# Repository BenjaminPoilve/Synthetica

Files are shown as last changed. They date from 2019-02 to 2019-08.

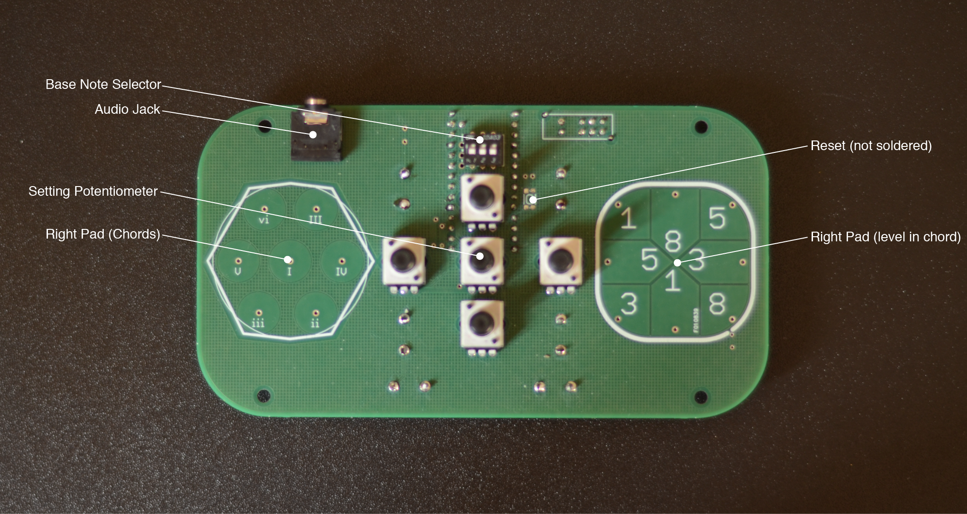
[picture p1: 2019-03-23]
Media/parts-02.png

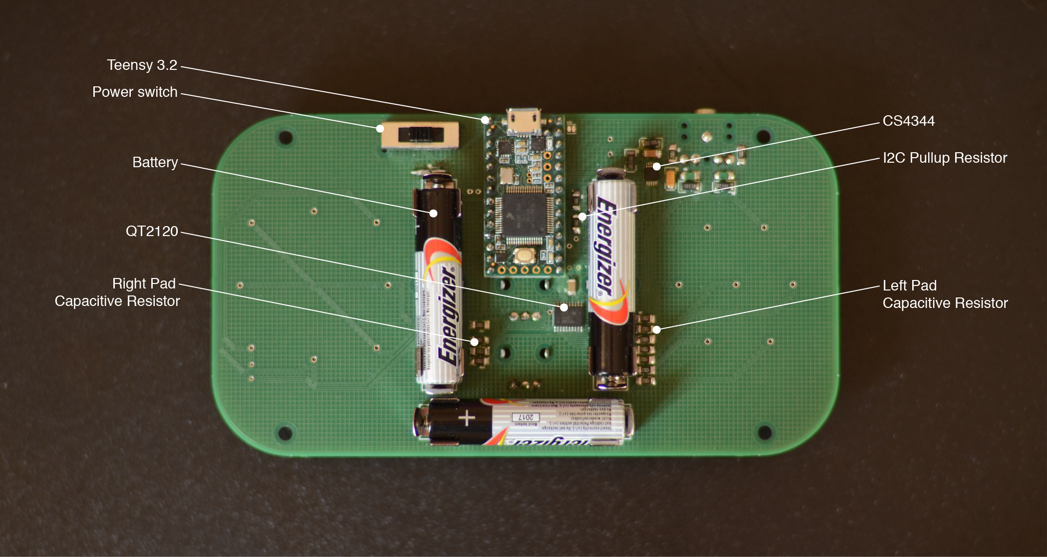
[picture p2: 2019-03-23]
Media/parts-01.png

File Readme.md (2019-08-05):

# Synthetica

**Read about this project [here](https://www.benjaminpoilve.com/projects/synthetica.html)**

The basic idea is to create a simple instrument, with on one side the chord selection, and on the other side the note selection (within that chord). 

I will use a teensy as main board for a few reason:

* Teensy are awesome
* Teensy audio library is awesome

Will be major only, minor by transposition as with the harmonica. Choice of chords, look [here](https://www.hooktheory.com/blog/i-analyzed-the-chords-of-1300-popular-songs-for-patterns-this-is-what-i-found/)

## BOM

The teensy 3.2 will do:

* I2S output (Pin 9,11,22,23)
* I2C to touch chip (Pin 18, 19)
* 5 setting potentiometer (Pin 14, 16, 17 ,20)
* 3 switch for fondamental select (Pin 2, 3, 4)
* 1 calibrate switch (Pin 5)
* 1 select switch (automatically go from jack to USB) (Pin 6)

#### Summing Up

| Part Name  |  Value | Reference document | Count | 
|---|---|---|---|
|  Teensy 3.2  | None  | [:link:](https://www.mouser.fr/ProductDetail/Adafruit/2756?qs=sGAEpiMZZMuSK2mCDyT9crBR9UUNDPltQqpZaqADC8g%3d) | 1  | 
| Potentiometer |  100K  | [:link:](https://www.mouser.fr/ProductDetail/Bourns/PTV09A-4020U-B104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)  | 5  |  
| 3 DIP switch | None  | [:link:](https://www.mouser.fr/ProductDetail/CK/SDA03H1BD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)  | 1  |  
| DP3T switch | None  | [:link:](https://www.mouser.fr/ProductDetail/CK/OS203012MU5QP1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)  | 1  |  
|CS4344| None  | [:link:](https://www.mouser.fr/ProductDetail/Cirrus-Logic/CS4344-CZZ?qs=sGAEpiMZZMuYaq4aOfOV%252bEKBckiASbBM)  | 1  |  
| QT2120 | None  | [:link:](https://www.mouser.fr/ProductDetail/Microchip-Technology-Atmel/AT42QT2120-XUR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)  | 1  | 
|KMR2 switch | None  | [:link:](https://www.mouser.fr/ProductDetail/CK/KMR231NGLFS?qs=sGAEpiMZZMsgGjVA3toVBPoYbSFtFlEEZ%2foF5FrvAI8%3d)  | 1  | 
|AAA Holder | None  | [:link:](https://www.mouser.fr/ProductDetail/Keystone-Electronics/82?qs=sGAEpiMZZMsQtlBhqKq43YbiTvCk46ni)  | 6  | 
| Jack Connector | None | [:link:](https://www.mouser.fr/ProductDetail/Switchcraft/35RAPC4BHN2?qs=sGAEpiMZZMv0W4pxf2HiV3fTUvSc3cBd2jSbOSYtPwc%3d) | 1|
| Capacitor | 0.1uf | [:link:](https://www.mouser.fr/ProductDetail/KEMET/C1206C104MMREC7210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) | 2|
| Polarised capacitor | 1uf | [:link:](https://www.mouser.fr/ProductDetail/AVX/F971E105MAAHT3?qs=sGAEpiMZZMukHu%252bjC5l7Yco8kKEM9uRbb54cngRv8Go%3d) | 1|
| Polarised capacitor | 3.3uf | [:link:](https://www.mouser.fr/ProductDetail/AVX/F971C335MAAHT3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) | 3|
| Polarised capacitor | 10uf | [:link:](https://www.mouser.fr/ProductDetail/KEMET/T491A106K016AT7280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) | 1|
| Diode | None | [:link:](https://www.mouser.fr/ProductDetail/ROHM-Semiconductor/RB160MM-40TFTR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) | 1|
| Resistor | 470 | [:link:](https://www.mouser.fr/ProductDetail/KOA-Speer/SG73G2BTTD4700D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) | 2|
| Resistor | 2k2 | [:link:](https://www.mouser.fr/ProductDetail/TE-Connectivity-Holsworthy/CRGP1206F2K2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) | 2|
| Resistor | 10k | [:link:](https://www.mouser.fr/ProductDetail/Yageo/AC1206FR-1010KL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) | 13|

## Issues, and feedbacks

#### From First PCB

* Get longer pad traces for chips. This version is reflow friendly, but hard to hand solder
* The interruptor is backward, issue with trace
* The voltage drop of the diode is too high! Wrong part? Had to bypass it.
* Pots are too big. Should change version
* Should use two AAA, use a voltage converter
* Should put component more to the center to make the side more easy to cover
* Issue with jack trace, does not go through PCB hole.
* See if there is feeback on the sensors.
* Should really try to avoid vias on capacitive lines. At least put them closer to the center

#### Other

* Issue with [USB](https://forum.pjrc.com/threads/54239-USB-Audio-Clicking-Noise/page3?highlight=noise+audio)
* Probably needs to have a status led

## Thanks and people that helped

* Everybody that helped me on [that thread](https://forum.pjrc.com/threads/55137-I2S-output-with-CS4344) 
* @otem for its polysynth

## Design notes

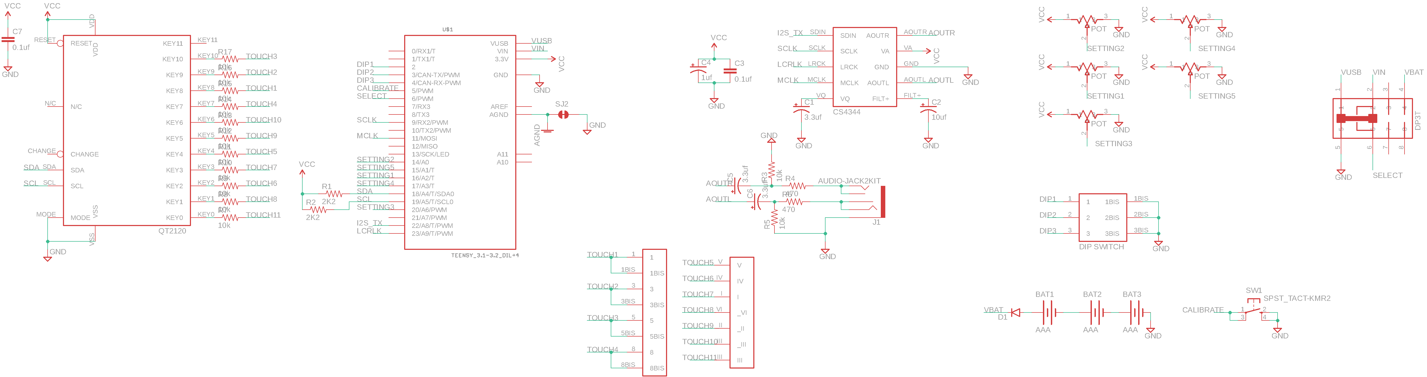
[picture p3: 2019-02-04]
Hardware/SCHEMATICS/Schematics.png

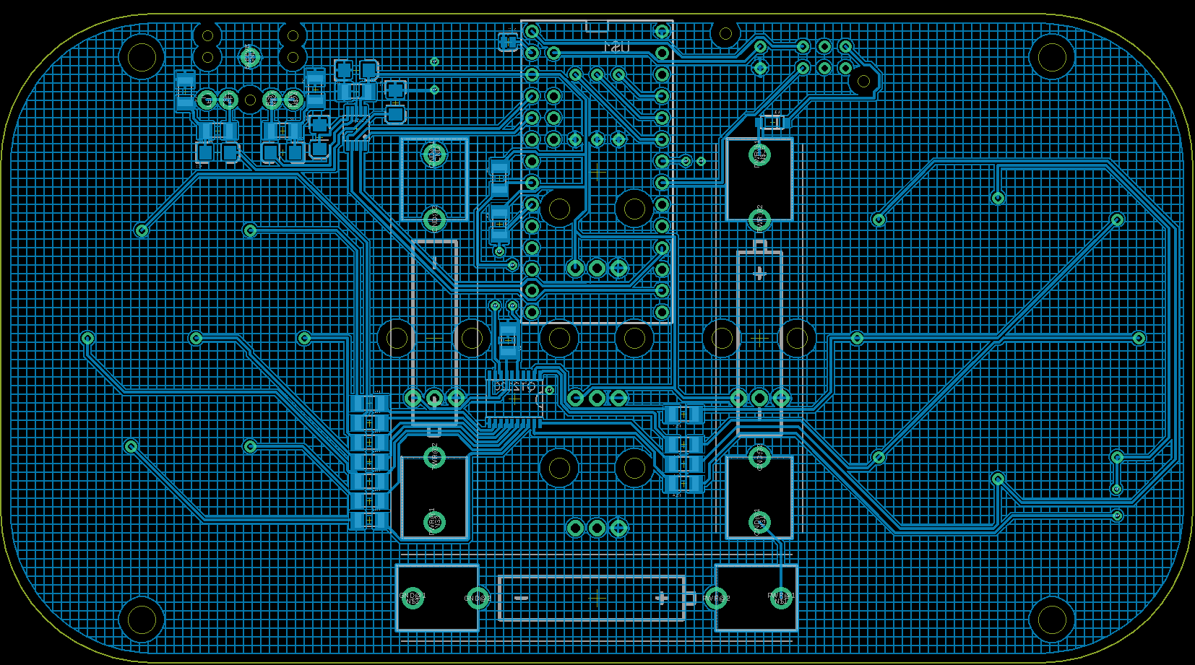
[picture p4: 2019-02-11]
Hardware/BOARD/bottom.png

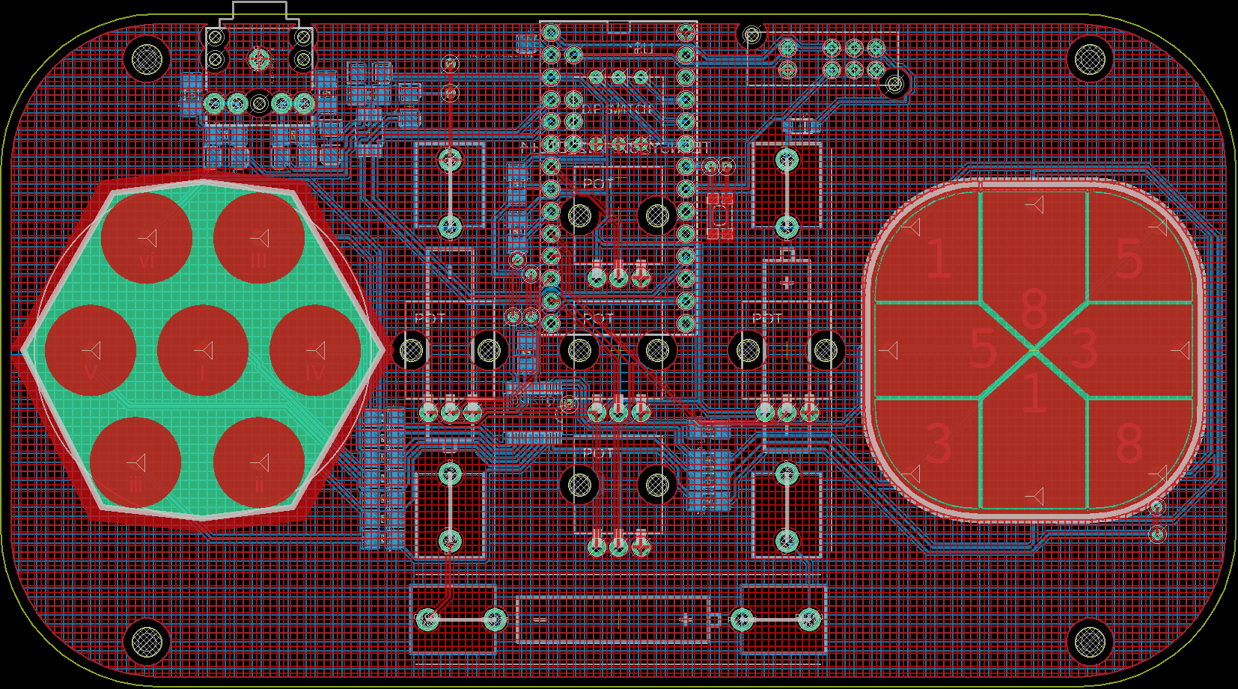
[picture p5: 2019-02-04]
Hardware/BOARD/board.png

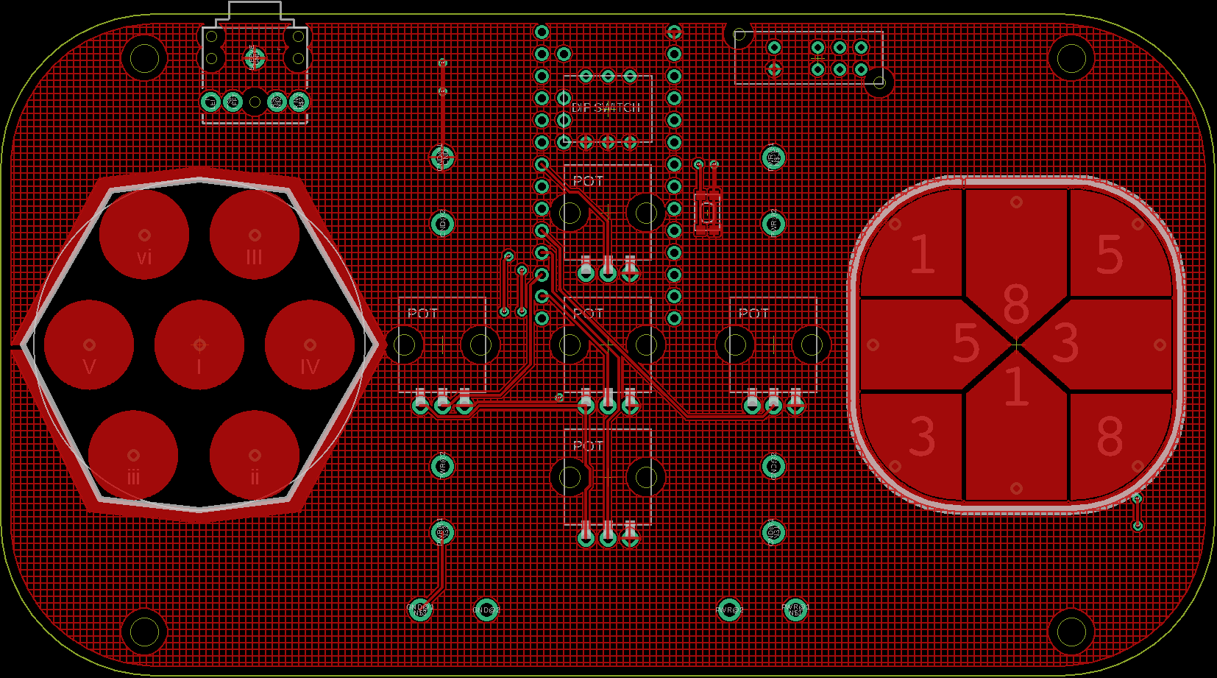
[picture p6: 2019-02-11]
Hardware/BOARD/top.png

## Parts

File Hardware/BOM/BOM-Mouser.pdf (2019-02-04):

Produits (https://www.mouser.fr/Electronic-Components/) | Fabricants (https://www.mouser.fr/supplierpage/) | Plus (https://www.mouser.fr/sitemap/) | Historique des commandes (https://www.mouser.fr/OrderHistory/OrderHistoryLogin.aspx) | Mon compte (https://www.mouser.fr/MyMouser/AccountSummary.aspx) | | | Déconnexion

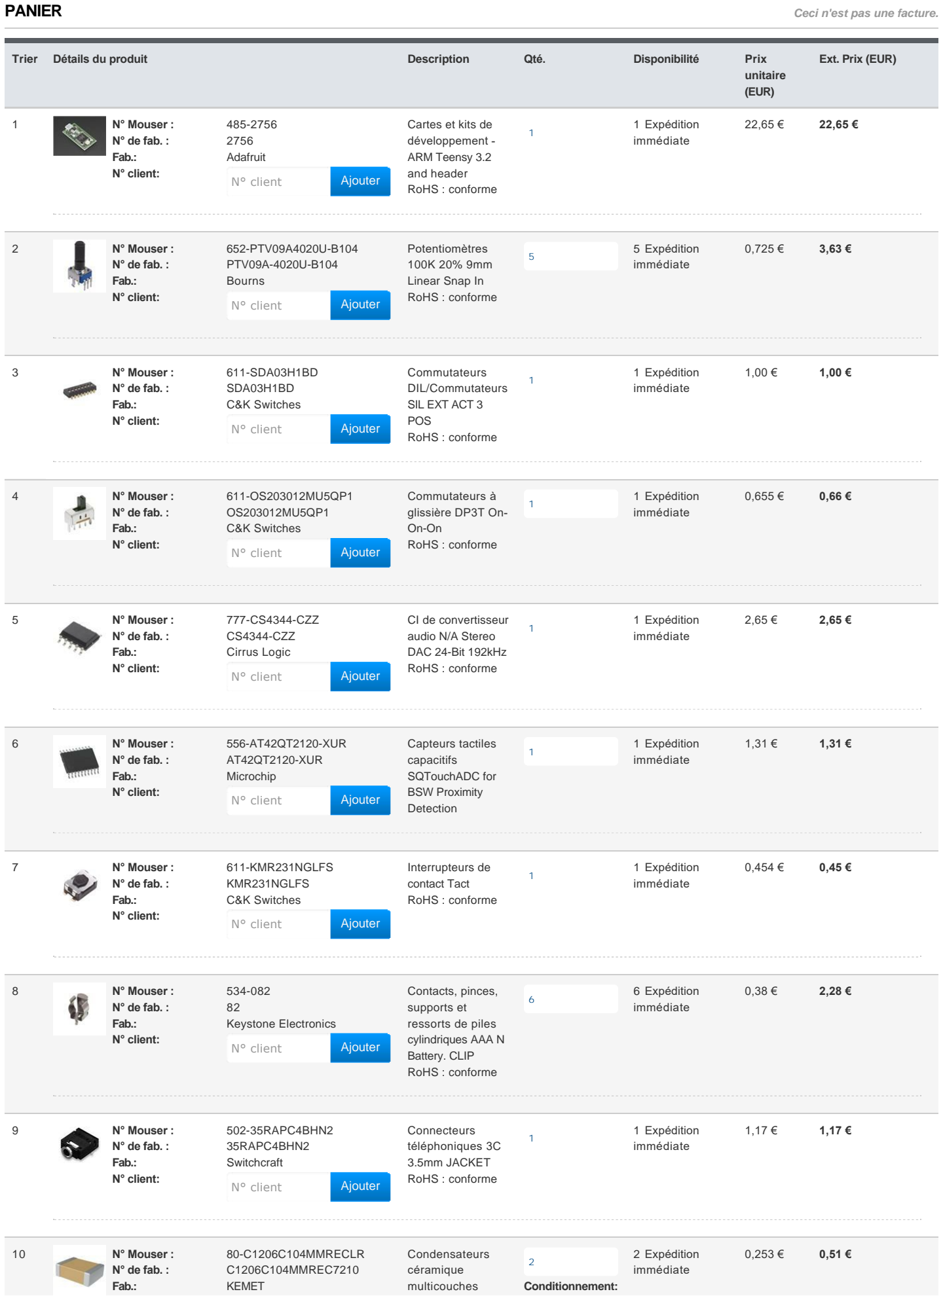
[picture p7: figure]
Trier; Détails du produit; Description; Qté.; Disponibilité; Prix; unitaire; (EUR); Ext. Prix (EUR); PANIER; Ceci n'est pas une facture.; N° Mouser :; N° de fab. :; Fab.:; Adafruit; N° client:; N° client; Ajouter; Cartes et kits de; développement; ARM Teensy 3.2; and header; RoHS : conforme; 1 Expédition; immédiate; 652-PTV09A4020U-B104; PTV09A-4020U-B104; Bourns; Potentiomètres; Linear Snap In; 5 Expédition; 611-SDA03H1BD; SDA03H1BD; C&K Switches; Commutateurs; DIL/Commutateurs; SIL EXT ACT 3; POS; Commutateurs à; glissière DP3T On-; 777-CS4344-CZZ; CS4344-CZZ; Cirrus Logic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

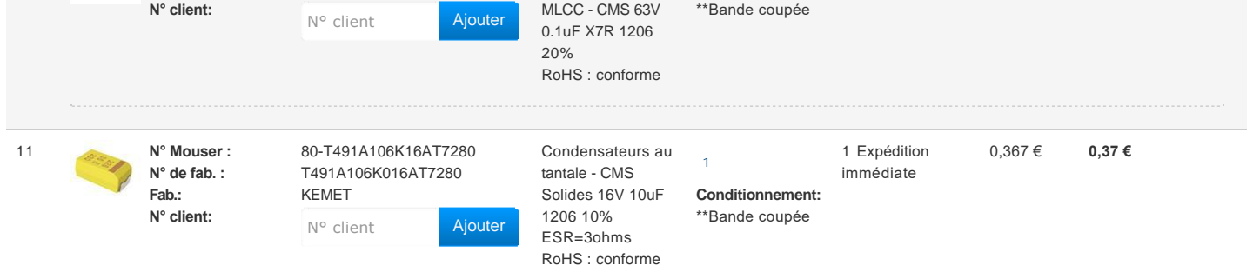
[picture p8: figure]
N° client:; N° client; Ajouter; MLCC - CMS 63V; RoHS : conforme; **Bande coupée; N° Mouser :; N° de fab. :; Fab.:; KEMET; Condensateurs au; tantale - CMS; Solides 16V 10uF; ESR=3ohms; Conditionnement:; 1 Expédition; immédiate
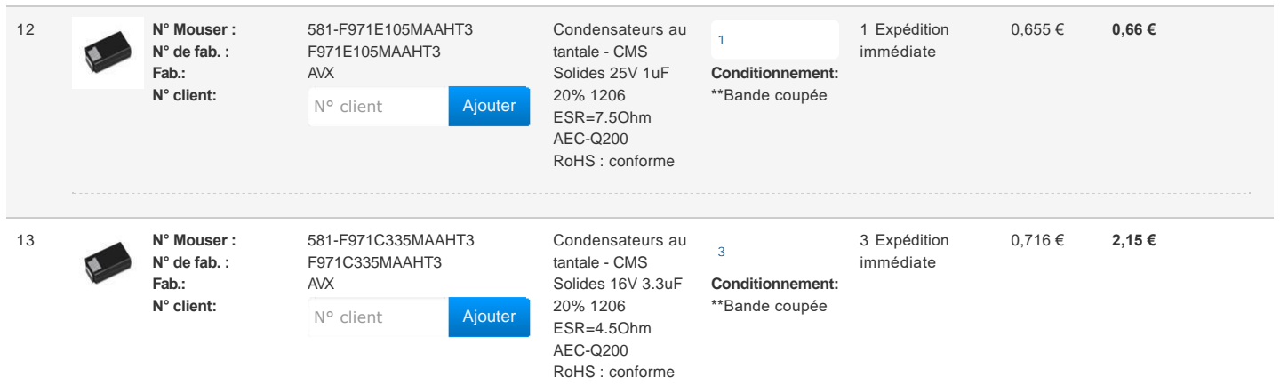
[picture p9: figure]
N° Mouser :; 581-F971E105MAAHT3; N° de fab. :; F971E105MAAHT3; Fab.:; AVX; N° client:; N° client; Ajouter; Condensateurs au; tantale - CMS; Solides 25V 1uF; ESR=7.5Ohm; AEC-Q200; RoHS : conforme; Conditionnement:; **Bande coupée; 1 Expédition; immédiate; 581-F971C335MAAHT3; F971C335MAAHT3; Solides 16V 3.3uF; ESR=4.5Ohm; 3 Expédition
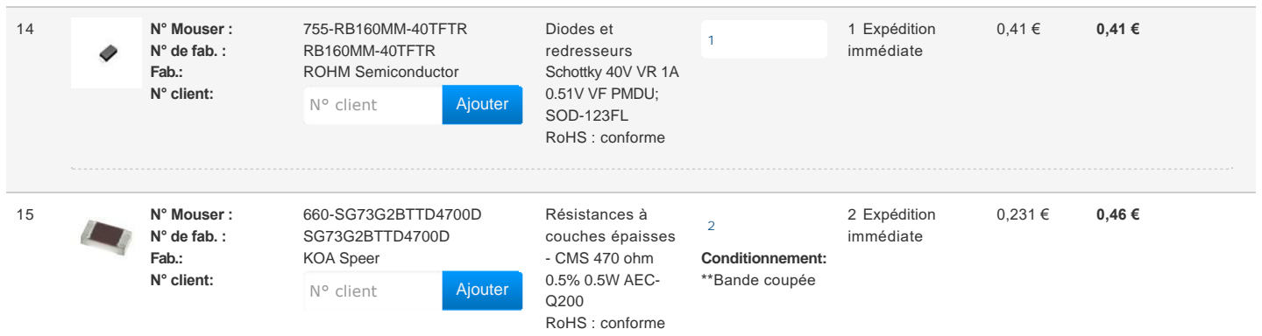
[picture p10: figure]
N° Mouser :; 755-RB160MM-40TFTR; N° de fab. :; RB160MM-40TFTR; Fab.:; ROHM Semiconductor; N° client:; N° client; Ajouter; Diodes et; redresseurs; Schottky 40V VR 1A; 0.51V VF PMDU;; SOD-123FL; RoHS : conforme; 1 Expédition; immédiate; 660-SG73G2BTTD4700D; SG73G2BTTD4700D; KOA Speer; Résistances à; couches épaisses; - CMS 470 ohm; 0.5% 0.5W AEC-; Conditionnement:; **Bande coupée; 2 Expédition
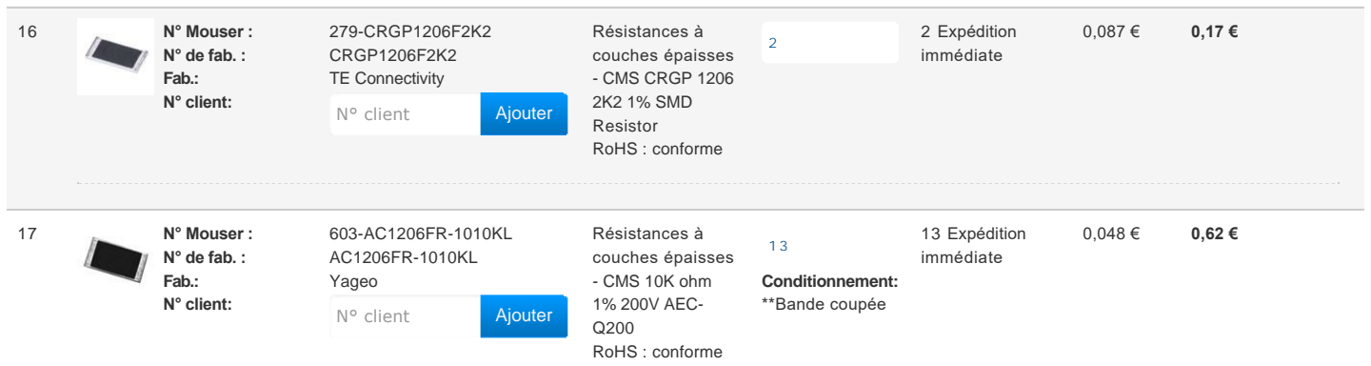
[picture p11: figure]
N° Mouser :; 279-CRGP1206F2K2; N° de fab. :; CRGP1206F2K2; Fab.:; TE Connectivity; N° client:; N° client; Ajouter; Résistances à; couches épaisses; - CMS CRGP 1206; 2K2 1% SMD; Resistor; RoHS : conforme; 2 Expédition; immédiate; Yageo; - CMS 10K ohm; 1% 200V AEC-; Conditionnement:; **Bande coupée; 13 Expédition

En soumettant votre commande, vous acceptez ces conditions. (https://www.mouser.fr/saleterms)
Pour plus d'informations sur la disponibilité, cliquez sur le numéro de référence Mouser

**Tous les articles MouseReel™ ne peuvent être ni annulés ni retournés.

Incoterms :DDP
Tous les prix incluent les taxes et les droits de douane pour les modes d'expédition sélectionnés.
Livraison gratuite pour la plupart des commandes supérieures à 50 € (EUR)
Total des articles : | 41,15 €
Estimation des frais d'expédition : | 20,00 € FedEx Inte
Sous-total : | 61,15 €

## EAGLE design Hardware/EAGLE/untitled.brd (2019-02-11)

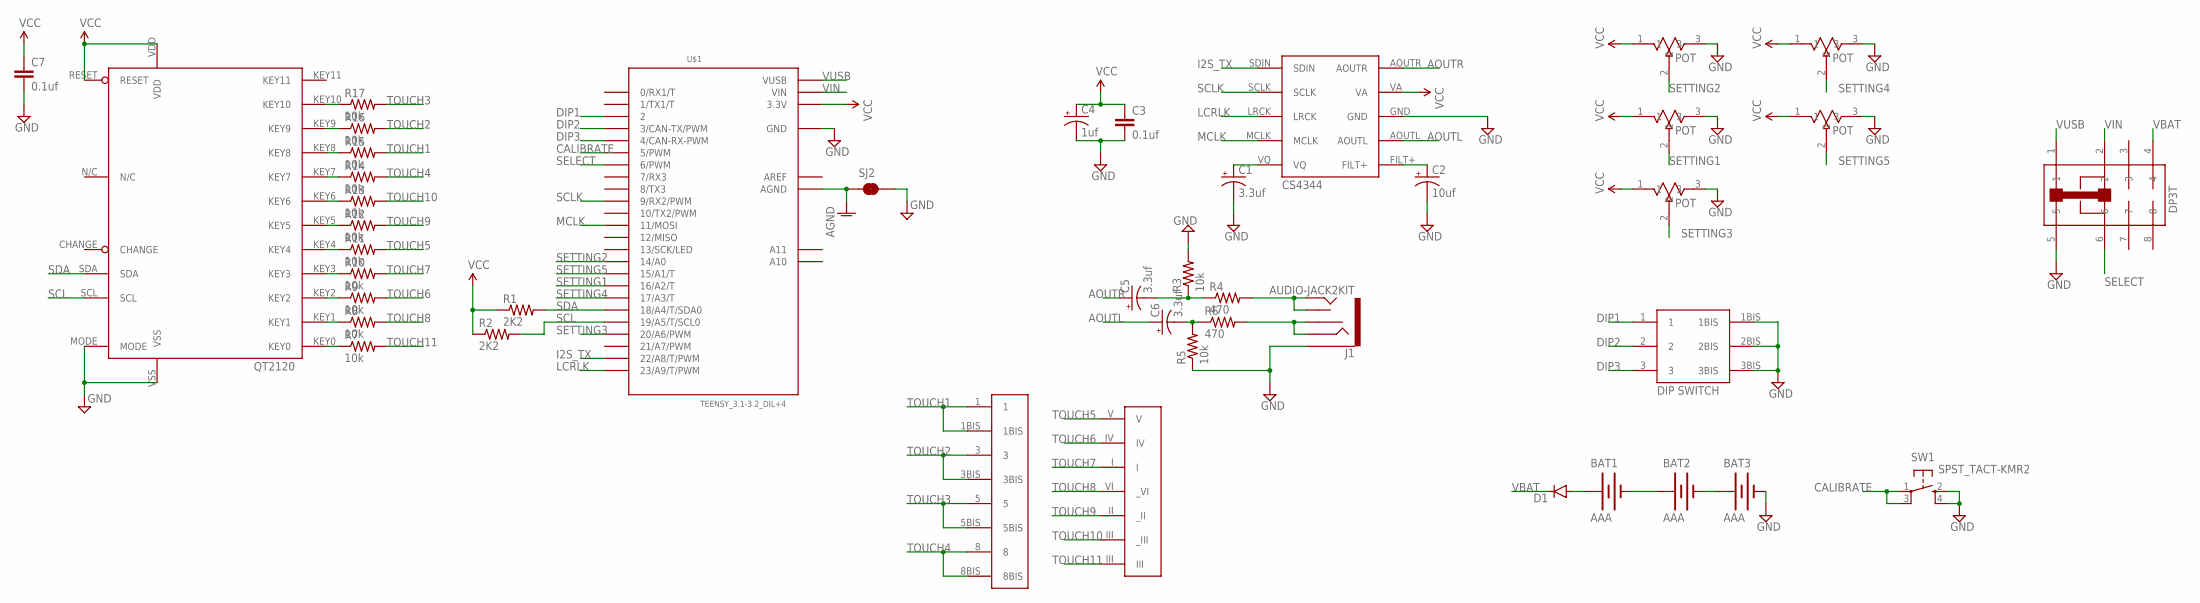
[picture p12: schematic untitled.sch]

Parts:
BAT1, BAT2, BAT3: AAA; BATTERY-AAA-KIT
C1, C5, C6: 3.3uf; EIA3216
C2: 10uf; EIA3216
C3, C7: 0.1uf; 1206
C4: 1uf; EIA3216
D1: DIODESOD123; SOD-123
DIP1: SDA03H1BD
DP3T1: OS203012MU5QP1
J1: AUDIO-JACK2KIT; AUDIO-JACK-KIT
POT2, POT3, POT5: PTV09A-4020U-B104
R1, R2: 2K2; 1206
R3, R5, R7, R8, R9, R10, R11, R12, R13, R14, R15, R16, R17: 10k; 1206
R4, R6: 470; 1206
SJ2: JUMPER-PAD-2-NC_BY_TRACE; PAD-JUMPER-2-NC_BY_TRACE_YES_SILK
SW1: SPST_TACT-KMR2; KMR2
SWEEP: PTV09A-4020U-B104
U1: CS4344
U$1: TEENSY_3.1-3.2_DIL+4; TEENSY_3.0-3.2&LC_DIL+4
U$2: QT2120
U$4: NOTEPAD
U$5: CHORDPAD
VOLUME: PTV09A-4020U-B104

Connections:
AGND: SJ2.1, U$1.AGND
AOUTL: C6.A (+), U1.AOUTL
AOUTR: C5.A (+), U1.AOUTR
AREF: U$1.AREF
CALIBRATE: SW1.1, SW1.3 (P1), U$1.5 (5/PWM)
DIP1: DIP1.1, U$1.2
DIP2: DIP1.2, U$1.3 (3/CAN-TX/PWM)
DIP3: DIP1.3, U$1.4 (4/CAN-RX-PWM)
GND: BAT3.GND@1 (-), C1.C (-), C2.C (-), C3.2, C4.C (-), C7.2, DIP1.1BIS, DIP1.2BIS, DIP1.3BIS, DP3T1.5, J1.SLEEVE, POT2.3, POT3.3, POT5.3, R3.2, R5.1, SJ2.2, SW1.2 (S), SW1.4 (S1), SWEEP.3, U1.GND, U$1.GND, U$2.MODE, U$2.VSS, VOLUME.3
I2S_TX: U1.SDIN, U$1.22/A8 (22/A8/T/PWM)
LCRLK: U1.LRCK, U$1.23/A9 (23/A9/T/PWM)
LEFT: J1.TIP, J1.TSH, R4.2
MCLK: U1.MCLK, U$1.11 (11/MOSI)
unnamed: BAT1.GND@1 (-), BAT2.PWR@1 (+)
unnamed: C1.A (+), U1.VQ
unnamed: BAT2.GND@1 (-), BAT3.PWR@1 (+)
unnamed: C2.A (+), U1.FILT+
unnamed: C5.C (-), R3.1, R4.1
unnamed: C6.C (-), R5.2, R6.1
unnamed: R17.1, U$2.KEY10
unnamed: R16.1, U$2.KEY9
unnamed: R15.1, U$2.KEY8
unnamed: R14.1, U$2.KEY7
unnamed: R13.1, U$2.KEY6
unnamed: R12.1, U$2.KEY5
unnamed: R11.1, U$2.KEY4
unnamed: R10.1, U$2.KEY3
unnamed: BAT1.PWR@1 (+), D1.A
unnamed: R9.1, U$2.KEY2
unnamed: R8.1, U$2.KEY1
unnamed: R7.1, U$2.KEY0
unnamed: J1.RING, J1.RSH, R6.2
SCL: R2.2, U$1.19/A5 (19/A5/T/SCL0), U$2.SCL
SCLK: U1.SCLK, U$1.9 (9/RX2/PWM)
SDA: R1.2, U$1.18/A4 (18/A4/T/SDA0), U$2.SDA
SELECT: DP3T1.6, U$1.6 (6/PWM)
SETTING1: POT2.2, U$1.16/A2 (16/A2/T)
SETTING2: U$1.14/A0, VOLUME.2
SETTING3: POT3.2, U$1.20/A6 (20/A6/PWM)
SETTING4: SWEEP.2, U$1.17/A3 (17/A3/T)
SETTING5: POT5.2, U$1.15/A1 (15/A1/T)
TOUCH1: R15.2, U$4.1, U$4.1BIS
TOUCH2: R16.2, U$4.3, U$4.3BIS
TOUCH3: R17.2, U$4.5, U$4.5BIS
TOUCH4: R14.2, U$4.8, U$4.8BIS
TOUCH5: R11.2, U$5.V
TOUCH6: R9.2, U$5.IV
TOUCH7: R10.2, U$5.I
TOUCH8: R8.2, U$5._VI
TOUCH9: R12.2, U$5._II
TOUCH10: R13.2, U$5._III
TOUCH11: R7.2, U$5.III
VBAT: D1.C, DP3T1.4
VCC: C3.1, C4.A (+), C7.1, POT2.1, POT3.1, POT5.1, R1.1, R2.1, SWEEP.1, U1.VA, U$1.3.3V, U$2.RESET, U$2.VDD, VOLUME.1
VIN: DP3T1.2, U$1.VIN
VUSB: DP3T1.1, U$1.VUSB

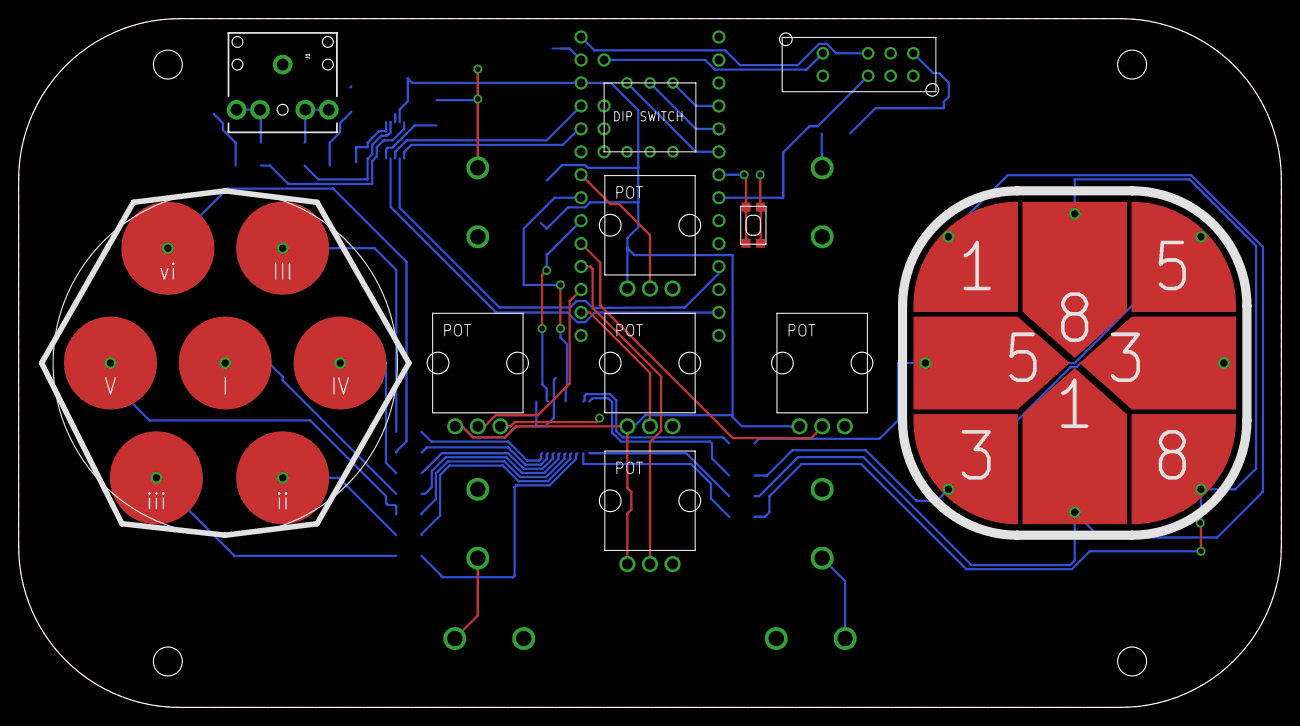
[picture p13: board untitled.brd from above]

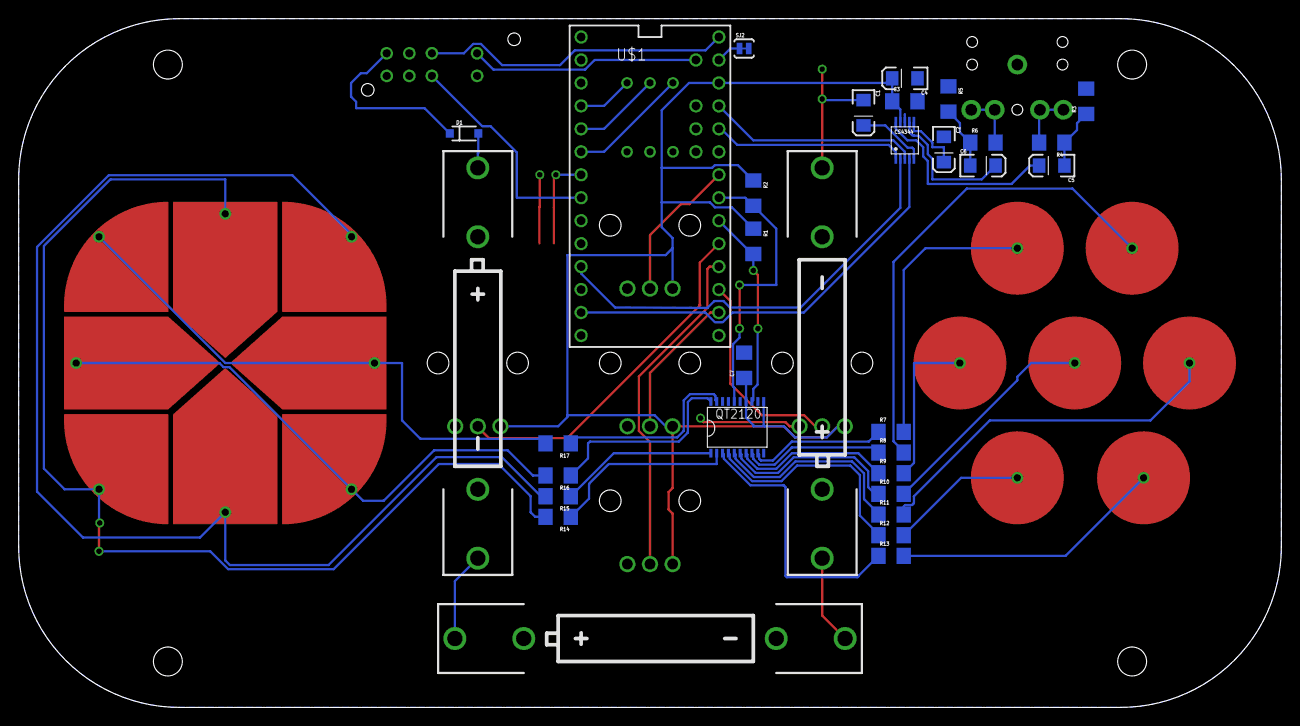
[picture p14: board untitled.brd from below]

Board: 2 copper layers, 139.7 x 76.2 mm, 43 parts (32 on the bottom side), 55 nets.

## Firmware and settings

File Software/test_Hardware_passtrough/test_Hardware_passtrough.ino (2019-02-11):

#include <Audio.h>
#include <Wire.h>
#include <SPI.h>
#include <SD.h>
#include <SerialFlash.h>

AudioInputUSB            usb1;           //xy=200,69  (must set Tools > USB Type to Audio)
AudioOutputI2S           i2s1;           //xy=365,94
AudioConnection          patchCord1(usb1, 0, i2s1, 0);
AudioConnection          patchCord2(usb1, 1, i2s1, 1);

void setup() {                
  AudioMemory(12);

}

void loop() {
  

  // use the scaled volume setting.  Delete this for fixed volume.

  delay(100);
}

// Teensyduino 1.35 & earlier had a problem with USB audio on Macintosh
// computers.  For more info and a workaround:
// https://forum.pjrc.com/threads/34855-Distorted-audio-when-using-USB-input-on-Teensy-3-1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

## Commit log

2019-02-01 Working my way on the part lists/trace
2019-02-04 V1 of board sent to fab
2019-02-11 Started assembly, updated eagles files
    [untitled.brd, untitled.sch]
2019-02-11 modded lib for all button support
2019-02-12 After first PCB assembly, feedback and new needs

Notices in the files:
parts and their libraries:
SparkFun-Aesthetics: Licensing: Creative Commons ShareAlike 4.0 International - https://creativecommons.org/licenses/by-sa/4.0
